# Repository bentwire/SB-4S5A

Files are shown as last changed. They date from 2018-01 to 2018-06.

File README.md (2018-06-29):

# SB-4S5A
4S1P 5000mAh smart battery

BOM: https://octopart.com/bom-tool/Ozuqnvew

![Image](https://lh3.googleusercontent.com/idjTSfCK8nfJFQzJIe7masI_trXQ7SMNvU6aqpUEBDsLIDIV-Hx3-JUPBGiGlPwAxTNEt7CckAo6dX-KWBZ0Mj_Hy6Guh6XXaXnfHWQ1HlrcL2ksQrWs3JgNRiBP9fyepql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)

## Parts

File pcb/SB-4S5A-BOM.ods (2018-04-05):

Qty | Line Item | Manufacturer | MPN | Octopart URL | Schematic Reference | Internal Part Number | Description | Total Qty (@ Batch Size: 10) | SKU | SKU | Packaging | Packaging | Unit Price (@ Batch Size: 10) | Unit Price (@ Batch Size: 10) | In Stock | In Stock | MOQ | MOQ | URL | URL | Distributor [Custom] | SKU [Custom] | Packaging [Custom] | Unit Price (@ Batch Size: 10) [Custom] | Line Total [Custom] | Batch Total [Custom] | In Stock [Custom] | MOQ [Custom] | URL [Custom] | Notes
 |  |  |  |  |  |  |  |  | Digi-Key | Mouser | Digi-Key | Mouser | Digi-Key | Mouser | Digi-Key | Mouser | Digi-Key | Mouser | Digi-Key | Mouser
2 | CSD17308Q3 | Texas Instruments | CSD17308Q3 | https://octopart.com/csd17308q3-texas+instruments-18530280 | Q1,Q2 |  |  | 20 | 296-27210-1-ND | CSD17308Q3 | Cut Tape |  | 0.904 | 0.676 | 23856 | 56 | 1 |  | https://octopart.com/click/track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 | https://octopart.com/click/track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 | Mouser | CSD17308Q3 |  | 0.676 | 1.352 | 13.52 | 56 |  | https://octopart.com/click/track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
1 | BQ40Z50RSMT-R1 | Texas Instruments | BQ40Z50RSMT-R1 | https://octopart.com/bq40z50rsmt-r1-texas+instruments-60770459 | U1 |  |  | 10 | 296-42424-1-ND | BQ40Z50RSMT-R1 | Cut Tape |  | 5.379 | 5.79 | 0 | 8385 | 1 |  | https://octopart.com/click/track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 | https://octopart.com/click/track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 | Digi-Key | 296-42424-1-ND | Cut Tape | 5.379 | 5.379 | 53.79 | 0 | 1 | https://octopart.com/click/track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
1 | 0.001 ohm 1% 1206 | Welwyn | LRMAM1206-R001FT5 | https://octopart.com/lrmam1206-r001ft5-welwyn-46392712 | R7 |  |  | 10 | 985-1544-1-ND | LRMAM1206-R001FT5 | Cut Tape |  | 0.404 | 0.38 | 5193 | 8269 | 1 |  | https://octopart.com/click/track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 | https://octopart.com/click/track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 | Mouser | LRMAM1206-R001FT5 |  | 0.38 | 0.38 | 3.8 | 8269 |  | https://octopart.com/click/track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
2 | 10K 1% 0402 | Yageo | RC0402FR-0710KL | https://octopart.com/rc0402fr-0710kl-yageo-55458461 | R15,R16 |  |  | 20 | 311-10.0KLRCT-ND | RC0402FR-0710KL | Cut Tape |  | 0.014 | 0.009 | 14082327 | 2372862 | 1 |  | https://octopart.com/click/track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 | https://octopart.com/click/track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 | Mouser | RC0402FR-0710KL |  | 0.009 | 0.018 | 0.18 | 2372862 |  | https://octopart.com/click/track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
2 | 5.1K 1% 0402 | Yageo | RC0402FR-075K1L | https://octopart.com/rc0402fr-075k1l-yageo-39844409 | R11,R14 |  |  | 20 | 311-5.10KLRCT-ND | RC0402FR-075K1L | Cut Tape |  | 0.014 | 0.009 | 1326600 | 308293 | 1 |  | https://octopart.com/click/track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 | https://octopart.com/click/track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 | Mouser | RC0402FR-075K1L |  | 0.009 | 0.018 | 0.18 | 308293 |  | https://octopart.com/click/track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
11 | 100 ohm 1% 0402 | Yageo | RC0402FR-07100RL | https://octopart.com/rc0402fr-07100rl-yageo-40952494 | R2,R3,R4,R5,R6,R8,R12,R17,R18,R19,R20 |  |  | 110 | 311-100LRCT-ND | RC0402FR-07100RL | Cut Tape |  | 0.0056 | 0.003 | 10041531 | 146034 | 1 |  | https://octopart.com/click/track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 | https://octopart.com/click/track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 | Digi-Key | 311-100LRCT-ND | Cut Tape | 0.0056 | 0.0616 | 0.616 | 10041531 | 1 | https://octopart.com/click/track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
2 | 10M 5% 0402 | Yageo | RC0402FR-0710ML | https://octopart.com/rc0402fr-0710ml-yageo-42336635 | R10,R13 |  |  | 20 | 311-10.0MLRCT-ND | RC0402FR-0710ML | Cut Tape |  | 0.013 | 0.01 | 530653 | 92341 | 1 |  | https://octopart.com/click/track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 | https://octopart.com/click/track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 | Mouser | RC0402FR-0710ML |  | 0.01 | 0.02 | 0.2 | 92341 |  | https://octopart.com/click/track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
4 | NTC THERMISTOR 10K OHM 1% 0402 | Murata | NCP15XH103F03RC | https://octopart.com/ncp15xh103f03rc-murata-746463 | TH1, TH2, TH3, TH4 |  |  | 40 | 490-4801-1-ND | NCP15XH103F03RC | Cut Tape |  | 0.0988 | 0.107 | 315244 | 140120 | 1 |  | https://octopart.com/click/track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 | https://octopart.com/click/track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 | Digi-Key | 490-4801-1-ND | Cut Tape | 0.0988 | 0.3952 | 3.952 | 315244 | 1 | https://octopart.com/click/track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
1 | BAT54HT1G | ON Semiconductor | BAT54HT1G | https://octopart.com/bat54ht1g-on+semiconductor-39616 | D1 |  |  | 10 | BAT54HT1GOSCT-ND | BAT54HT1G | Cut Tape |  | 0.225 | 0.167 | 150710 | 19391 | 1 |  | https://octopart.com/click/track?country=US&ak=68b25f31&sig=07c835d&sid=459&ppid=39616&vpid=1203010&ct=offers | https://octopart.com/click/track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 | Mouser | BAT54HT1G |  | 0.167 | 0.167 | 1.67 | 19391 |  | https://octopart.com/click/track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
1 | 2V7002LT1G | ON Semiconductor | 2V7002LT1G | https://octopart.com/2v7002lt1g-on+semiconductor-22133360 | Q3 |  |  | 10 | 2V7002LT1GOSCT-ND | 2V7002LT1G | Cut Tape |  | 0.251 | 0.16 | 100230 | 11900 | 1 |  | https://octopart.com/click/track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 | https://octopart.com/click/track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 | Digi-Key | 2V7002LT1GOSCT-ND | Cut Tape | 0.251 | 0.251 | 2.51 | 100230 | 1 | https://octopart.com/click/track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
1 | 0 ohm jumper 0402 | Yageo | RC0402JR-070RL | https://octopart.com/rc0402jr-070rl-yageo-55434392 | R1 |  |  | 10 | 311-0.0JRCT-ND | RC0402JR-070RL | Cut Tape |  | 0.01 | 0.009 | 0 | 1889345 | 1 |  | https://octopart.com/click/track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 | https://octopart.com/click/track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 | Mouser | RC0402JR-070RL |  | 0.009 | 0.009 | 0.09 | 1889345 |  | https://octopart.com/click/track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
5 | 0.1uF 25V X5R/X7R | TDK | C1005X5R1H104K050BB | https://octopart.com/c1005x5r1h104k050bb-tdk-25947547 | C1,C2,C3,C4,C5 |  |  | 10 | 445-5942-1-ND | C1005X5R1H104K050BB | Cut Tape |  | 0.093 | 0.091 | 3757988 | 146262 | 1 |  | https://octopart.com/click/track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 | https://octopart.com/click/track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 | Mouser | C1005X5R1H104K050BB |  | 0.091 | 0.091 | 0.91 | 146262 |  | https://octopart.com/click/track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
1 | 2.2uF 10V X5R/X7R | Murata | GCM1555C1H680JA16D | https://octopart.com/gcm1555c1h680ja16d-murata-7894738 | C6 |  |  | 10 | 490-12653-1-ND | GCM1555C1H680JA16D | Cut Tape |  | 0.05 | 0.052 | 55591 | 43435 | 1 |  | https://octopart.com/click/track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 | https://octopart.com/click/track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 | Digi-Key | 490-12653-1-ND | Cut Tape | 0.05 | 0.05 | 0.5 | 55591 | 1 | https://octopart.com/click/track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
34

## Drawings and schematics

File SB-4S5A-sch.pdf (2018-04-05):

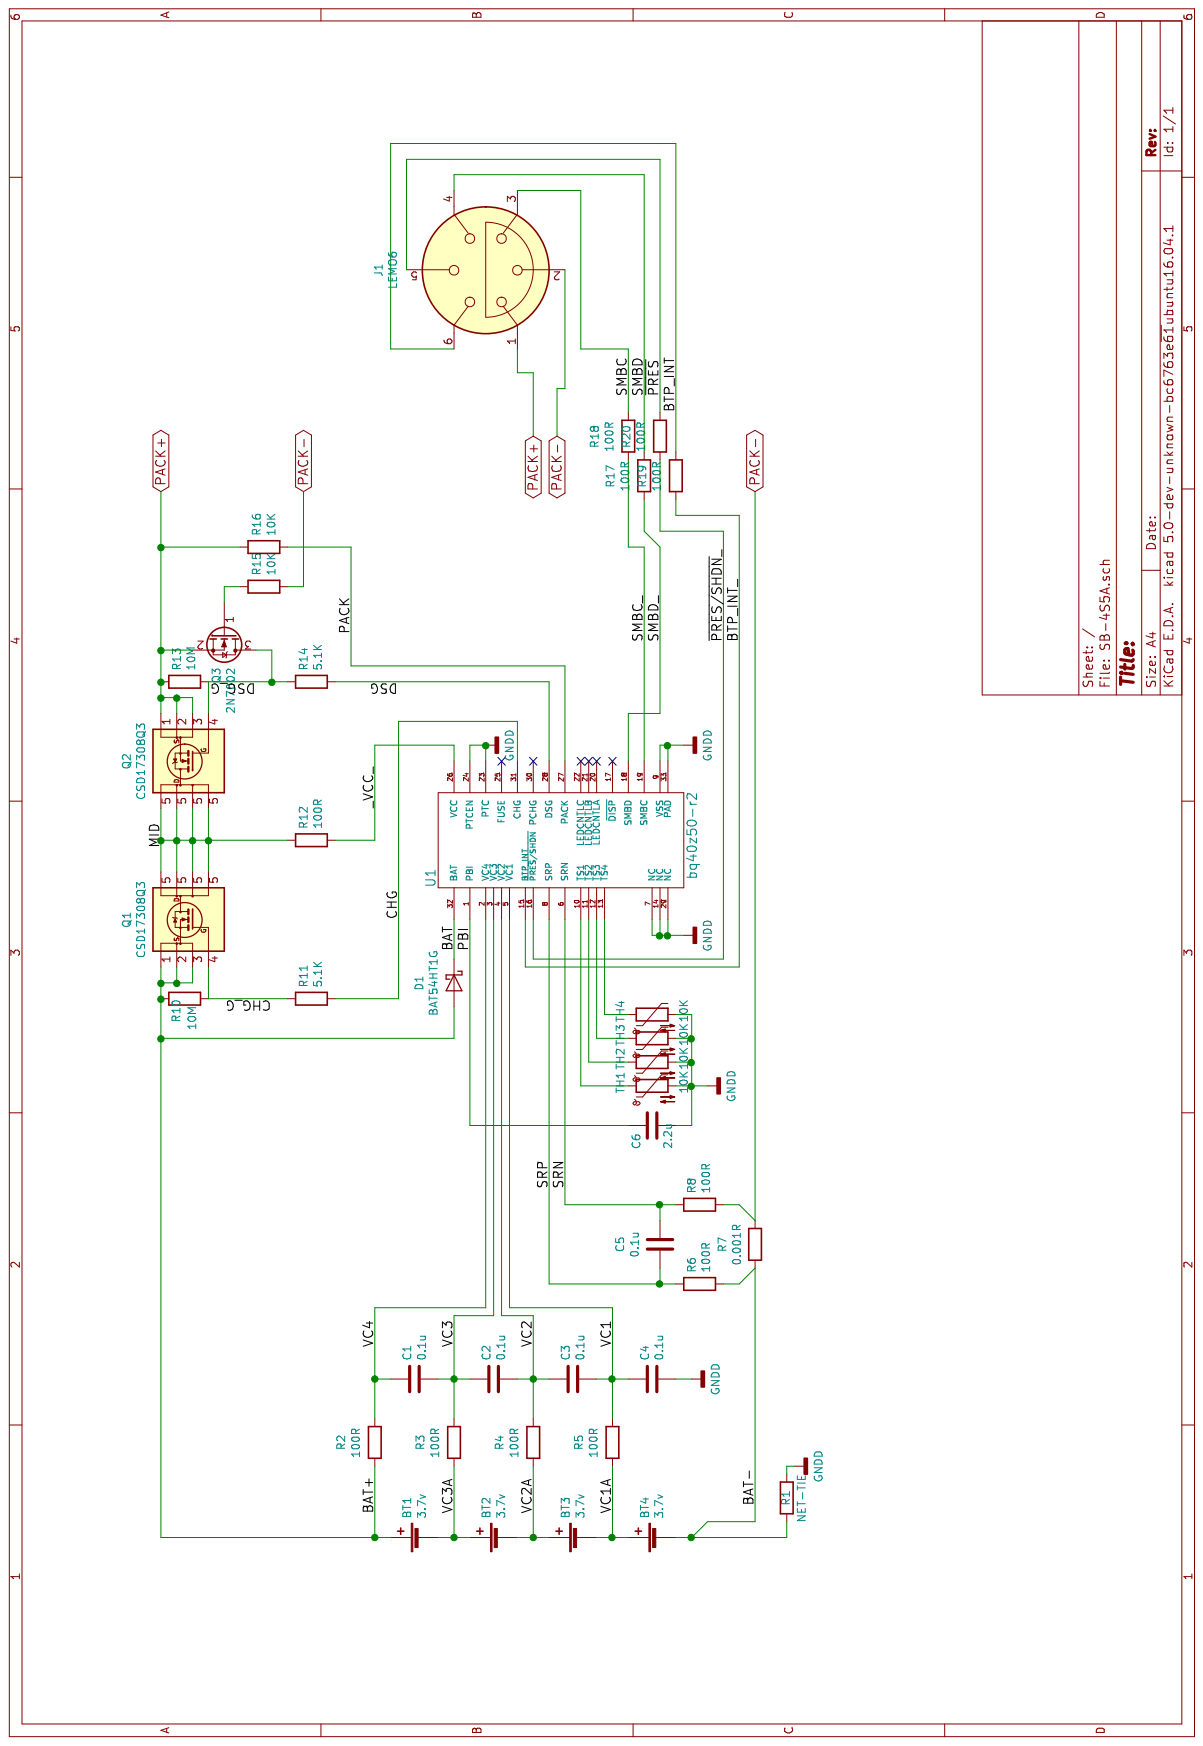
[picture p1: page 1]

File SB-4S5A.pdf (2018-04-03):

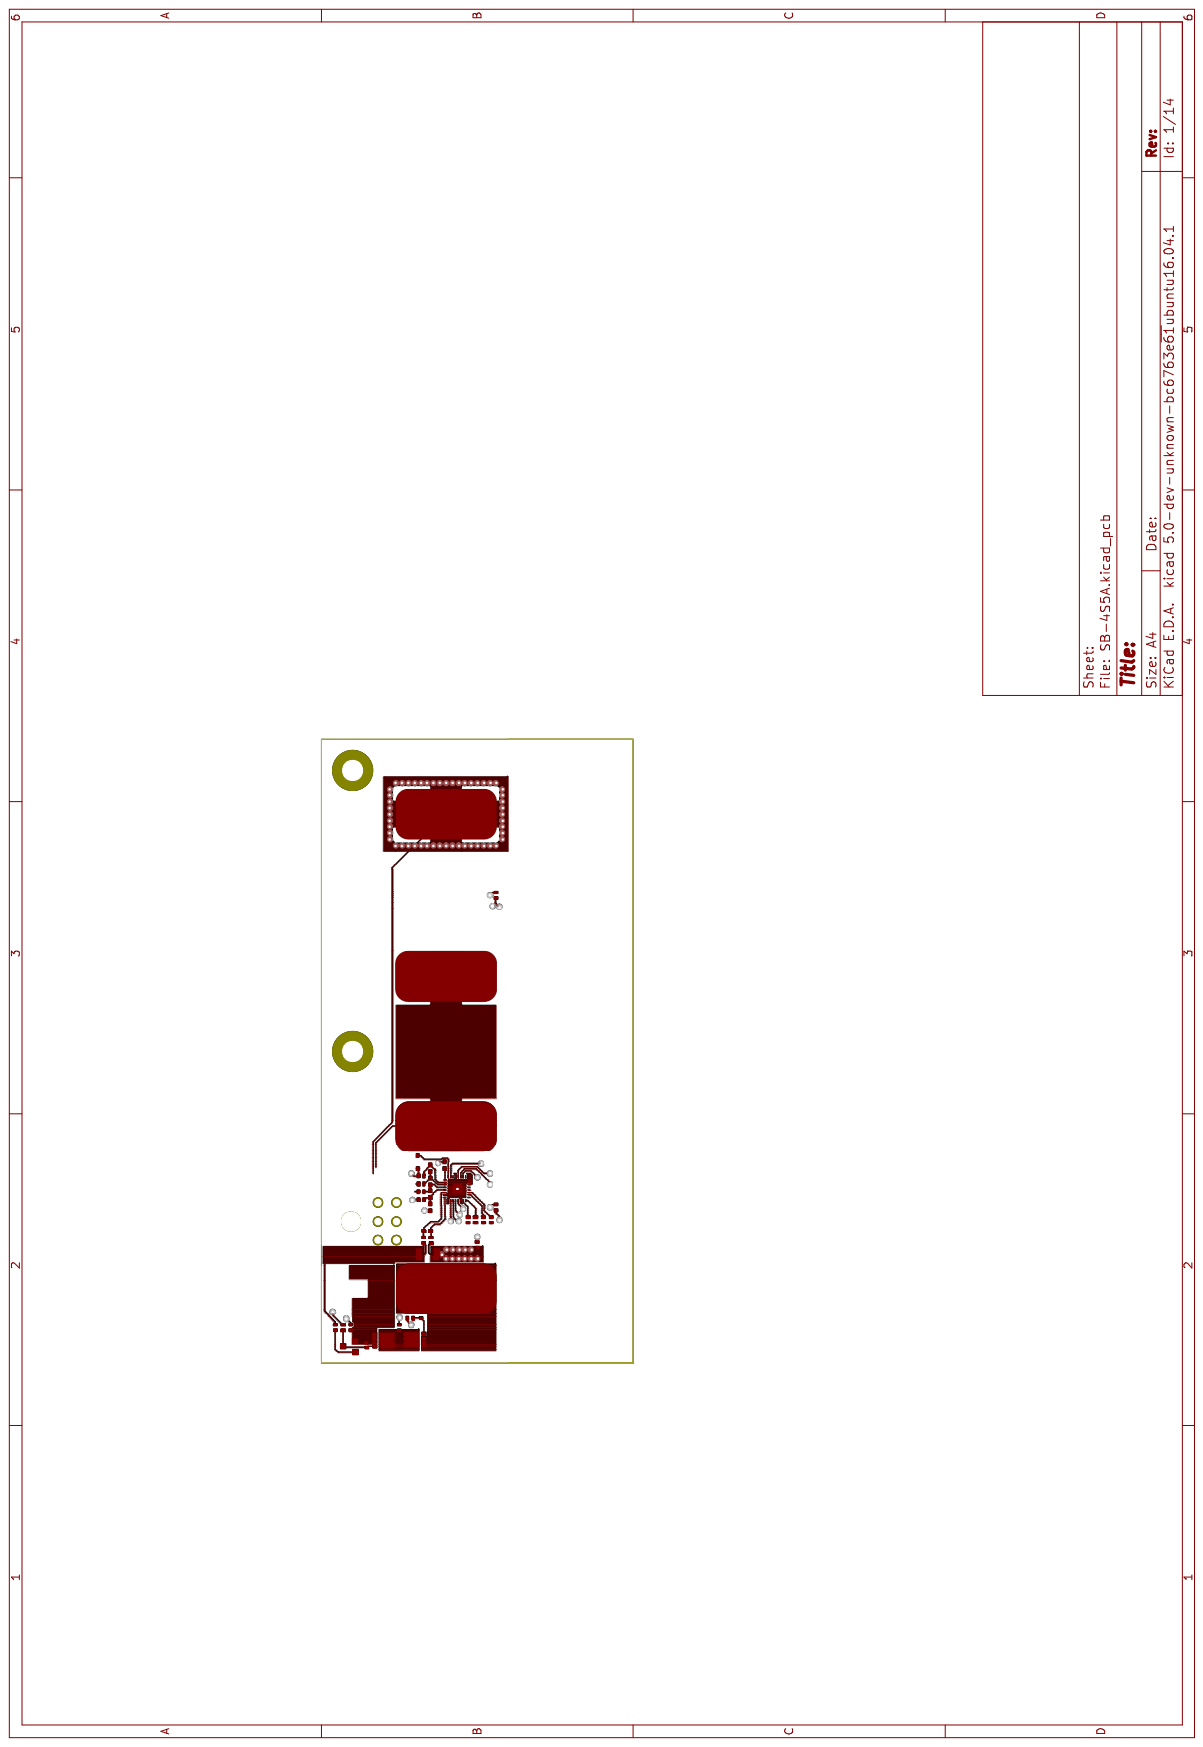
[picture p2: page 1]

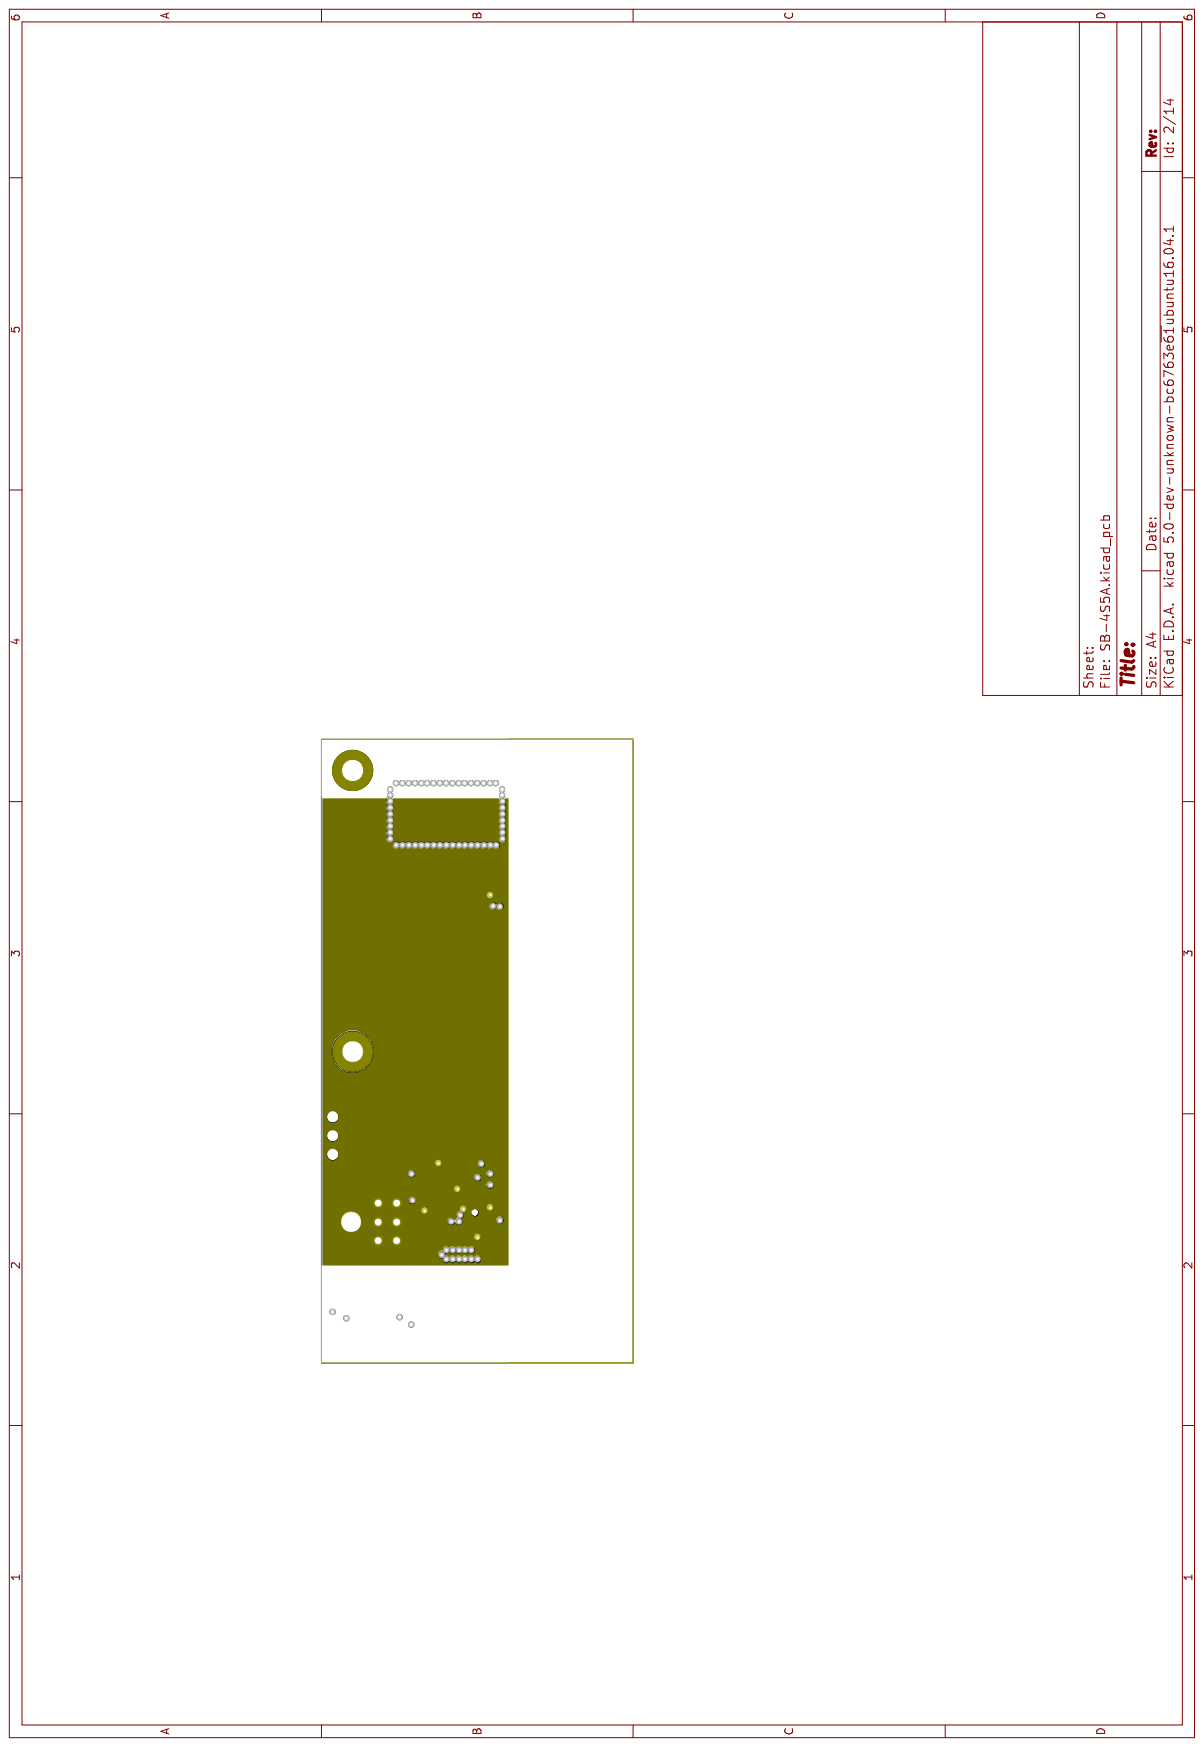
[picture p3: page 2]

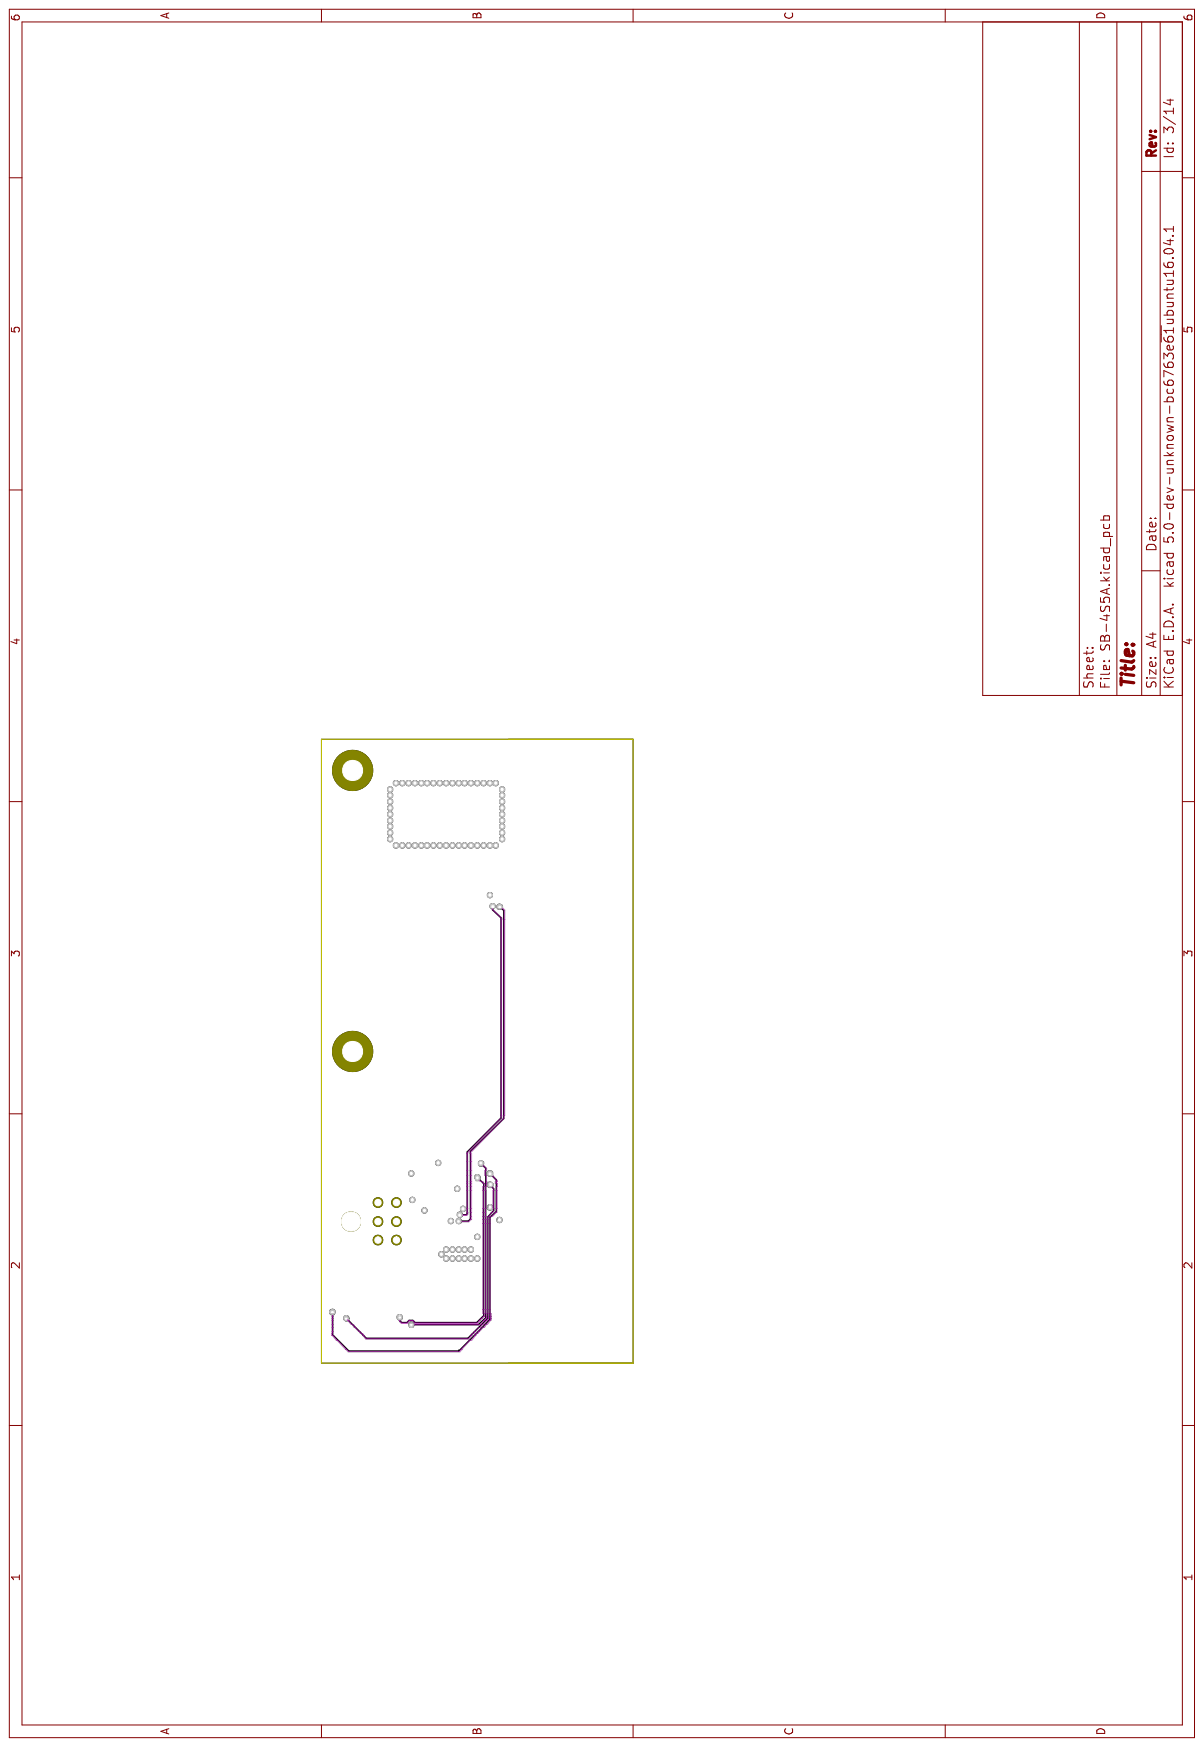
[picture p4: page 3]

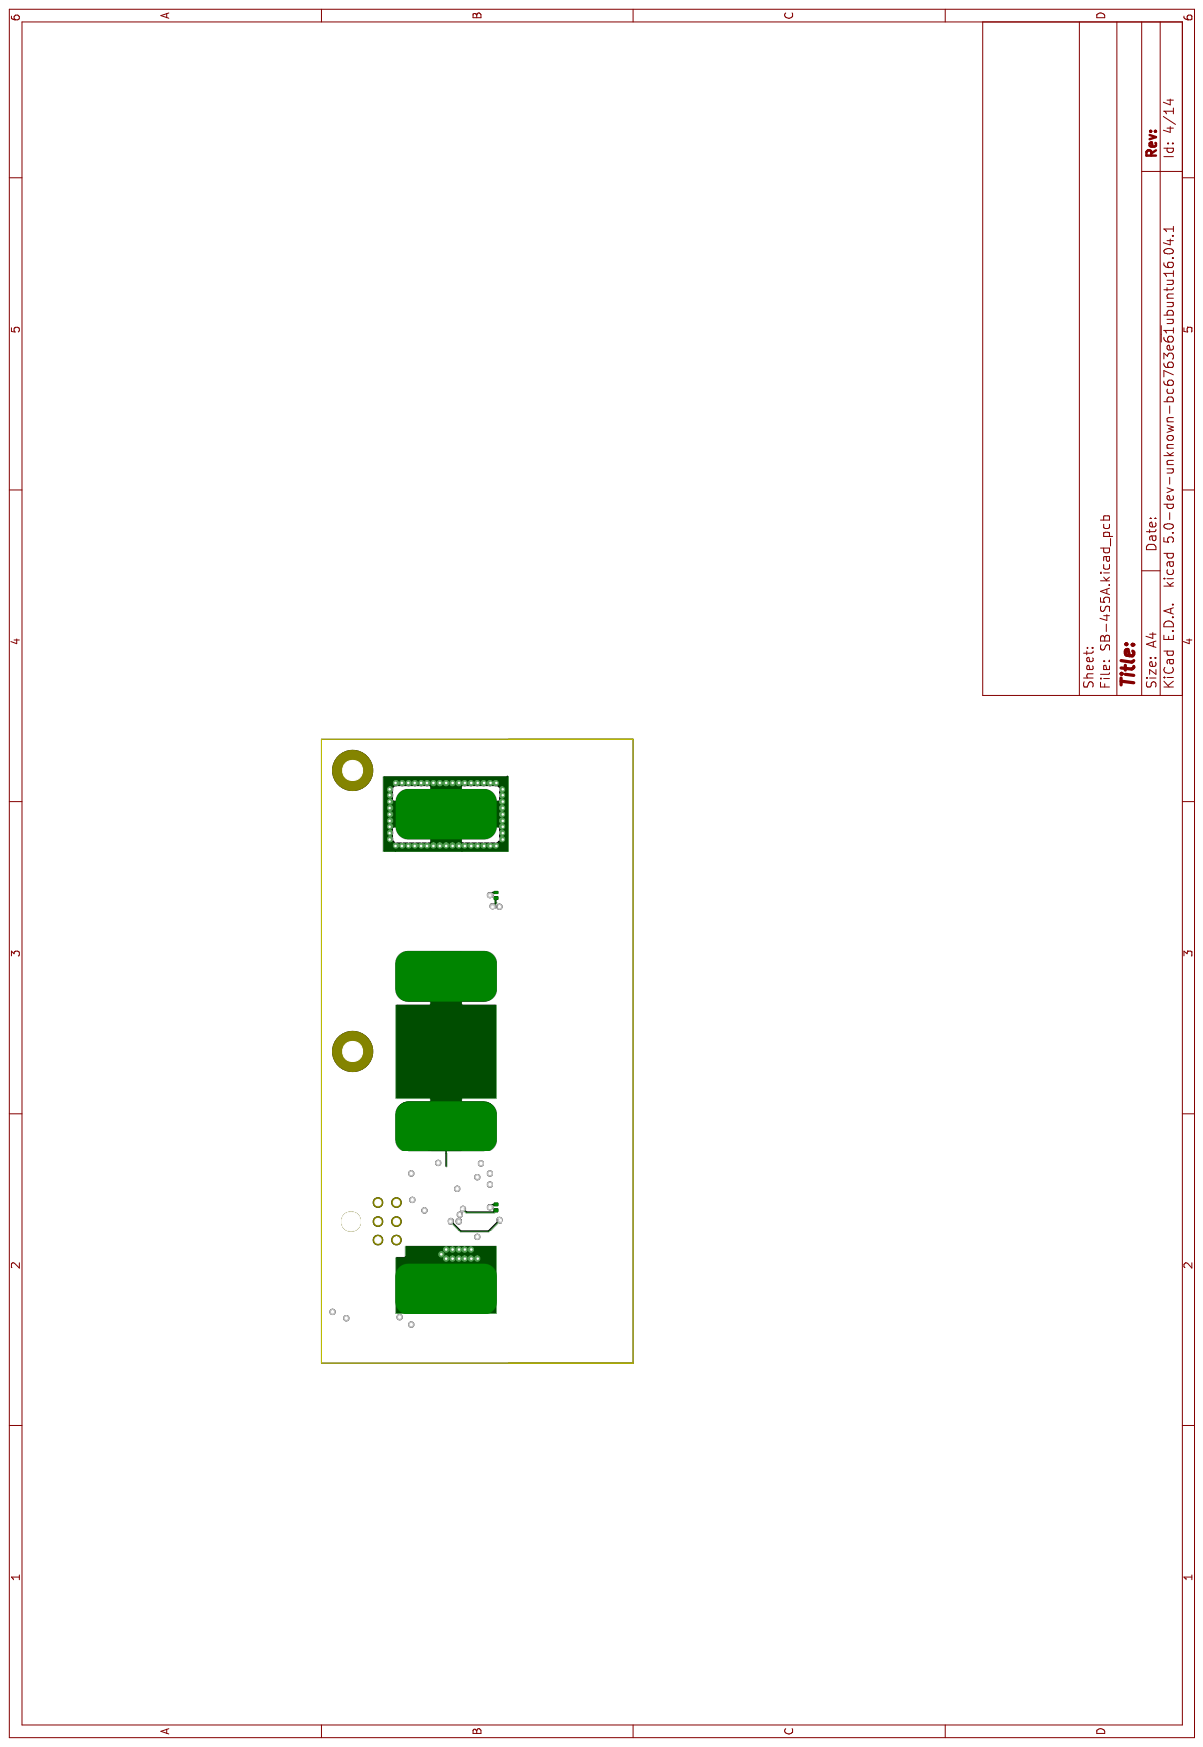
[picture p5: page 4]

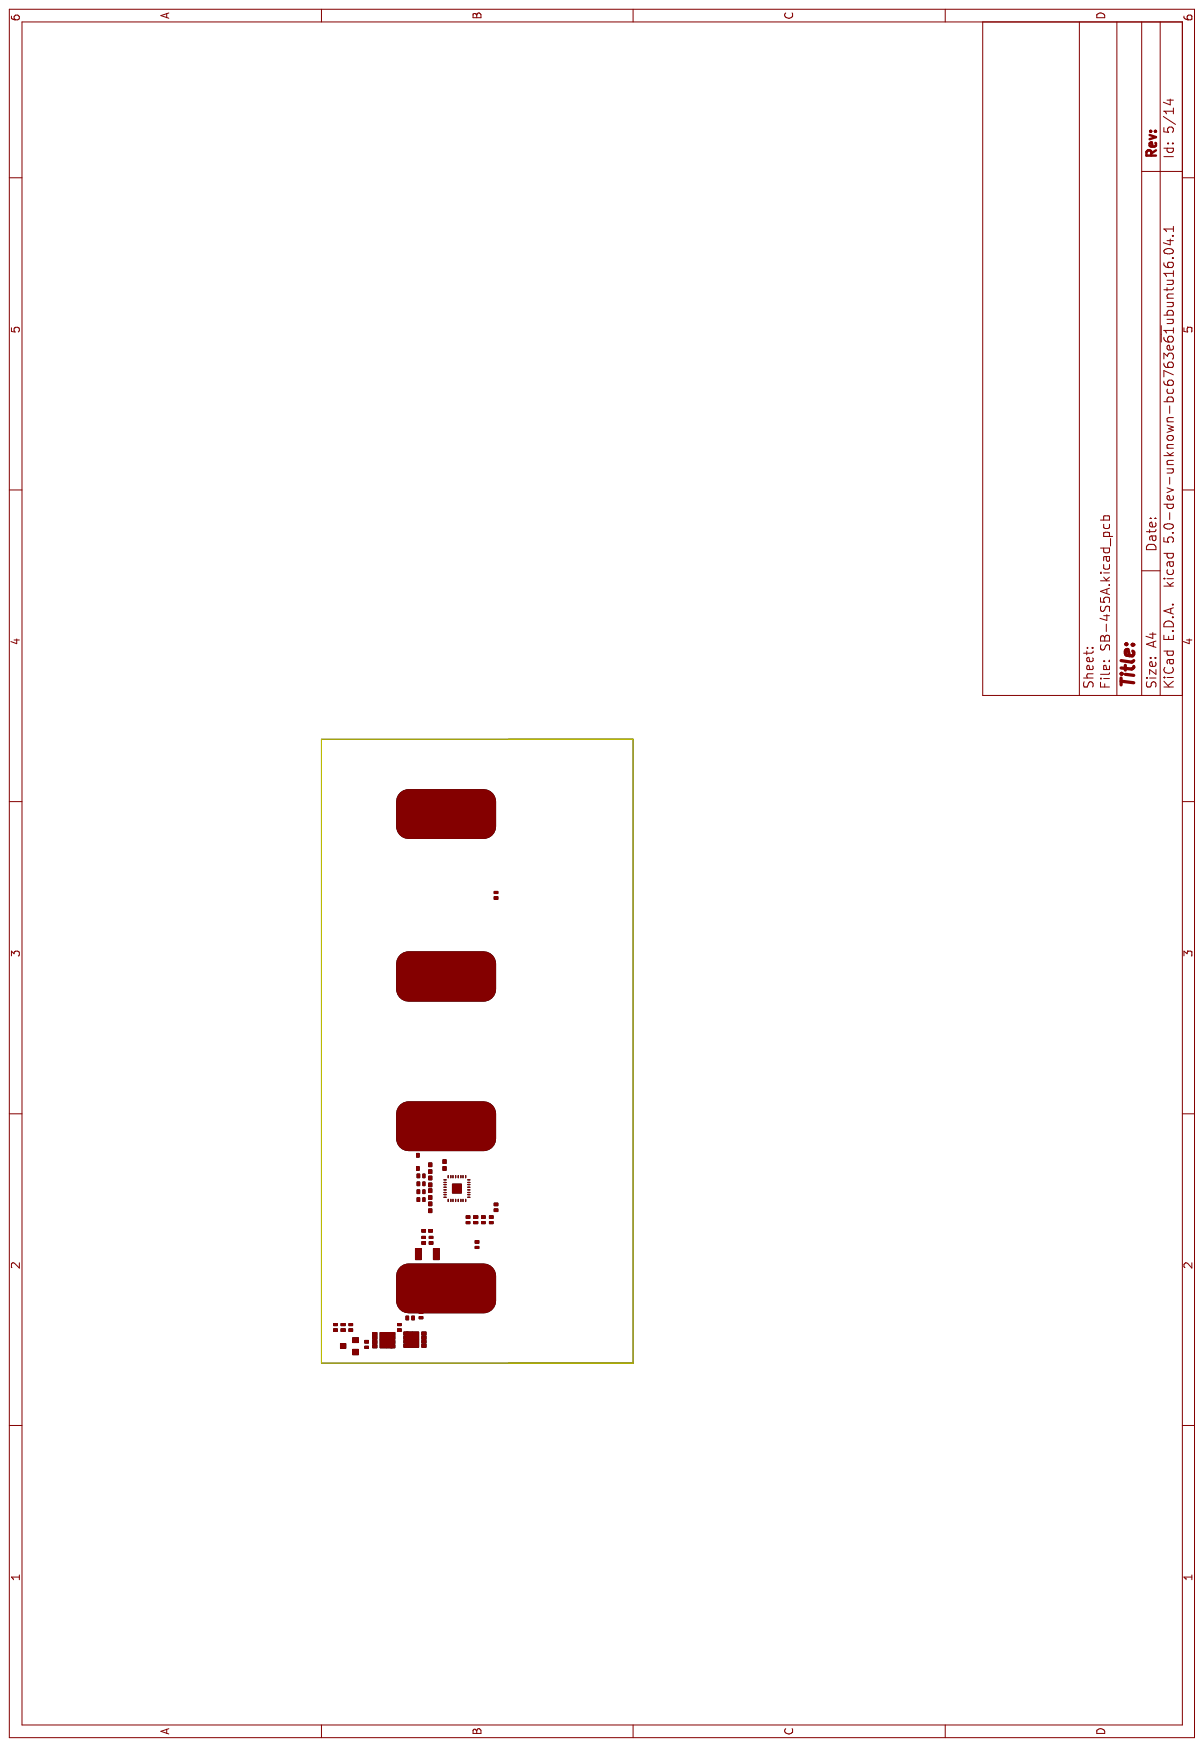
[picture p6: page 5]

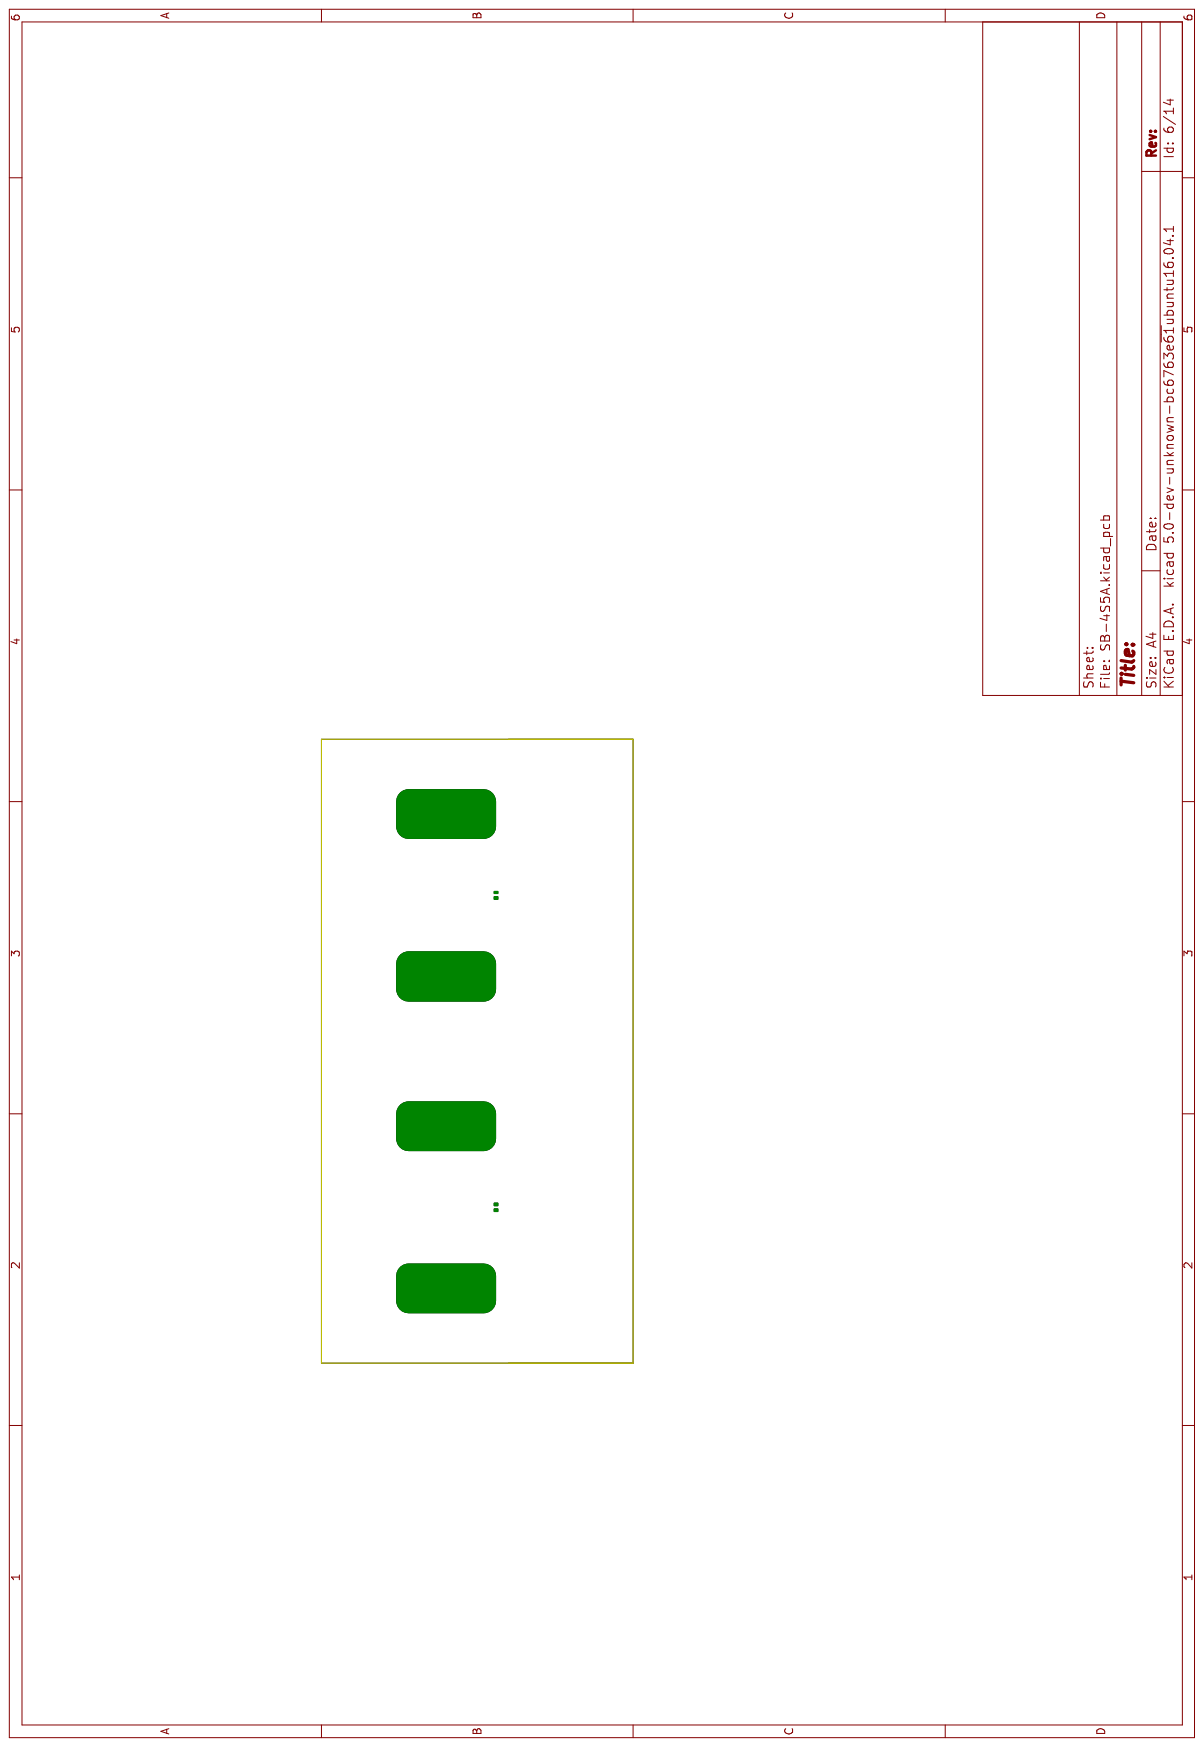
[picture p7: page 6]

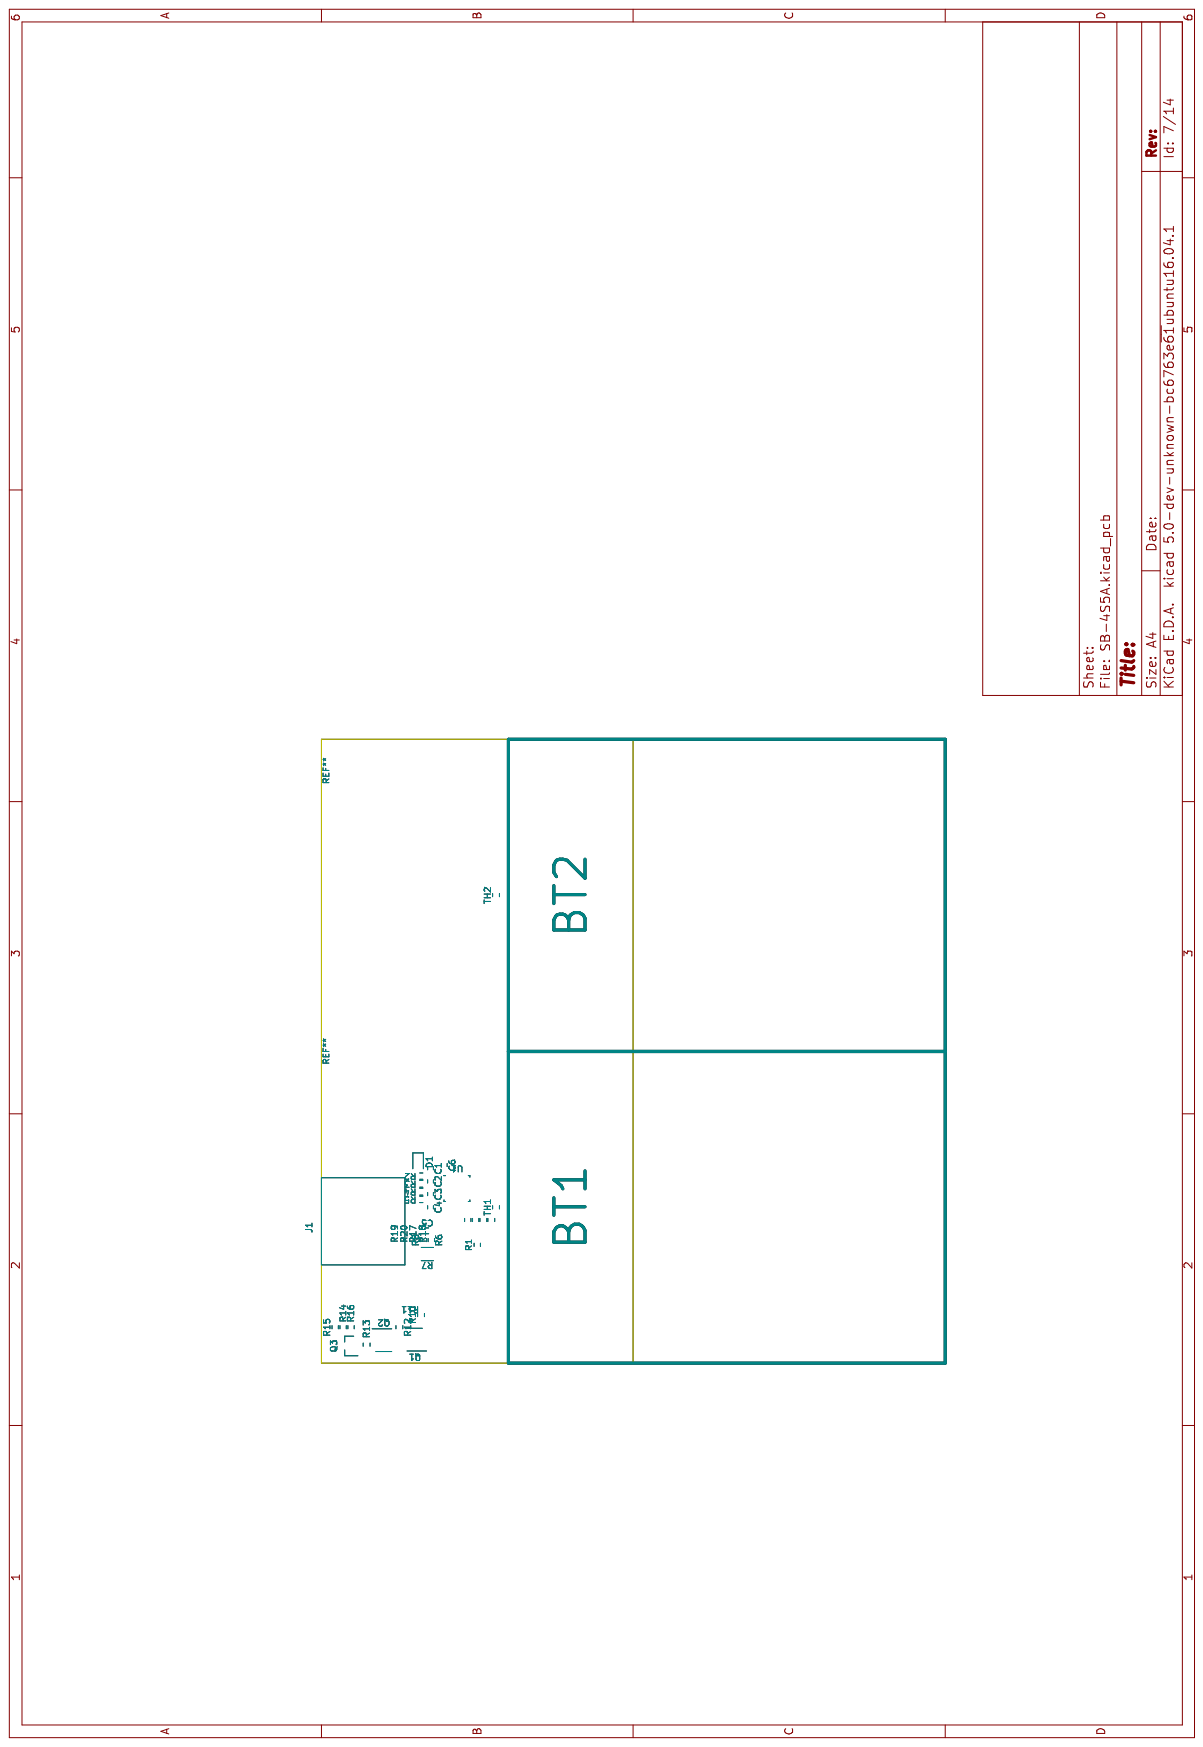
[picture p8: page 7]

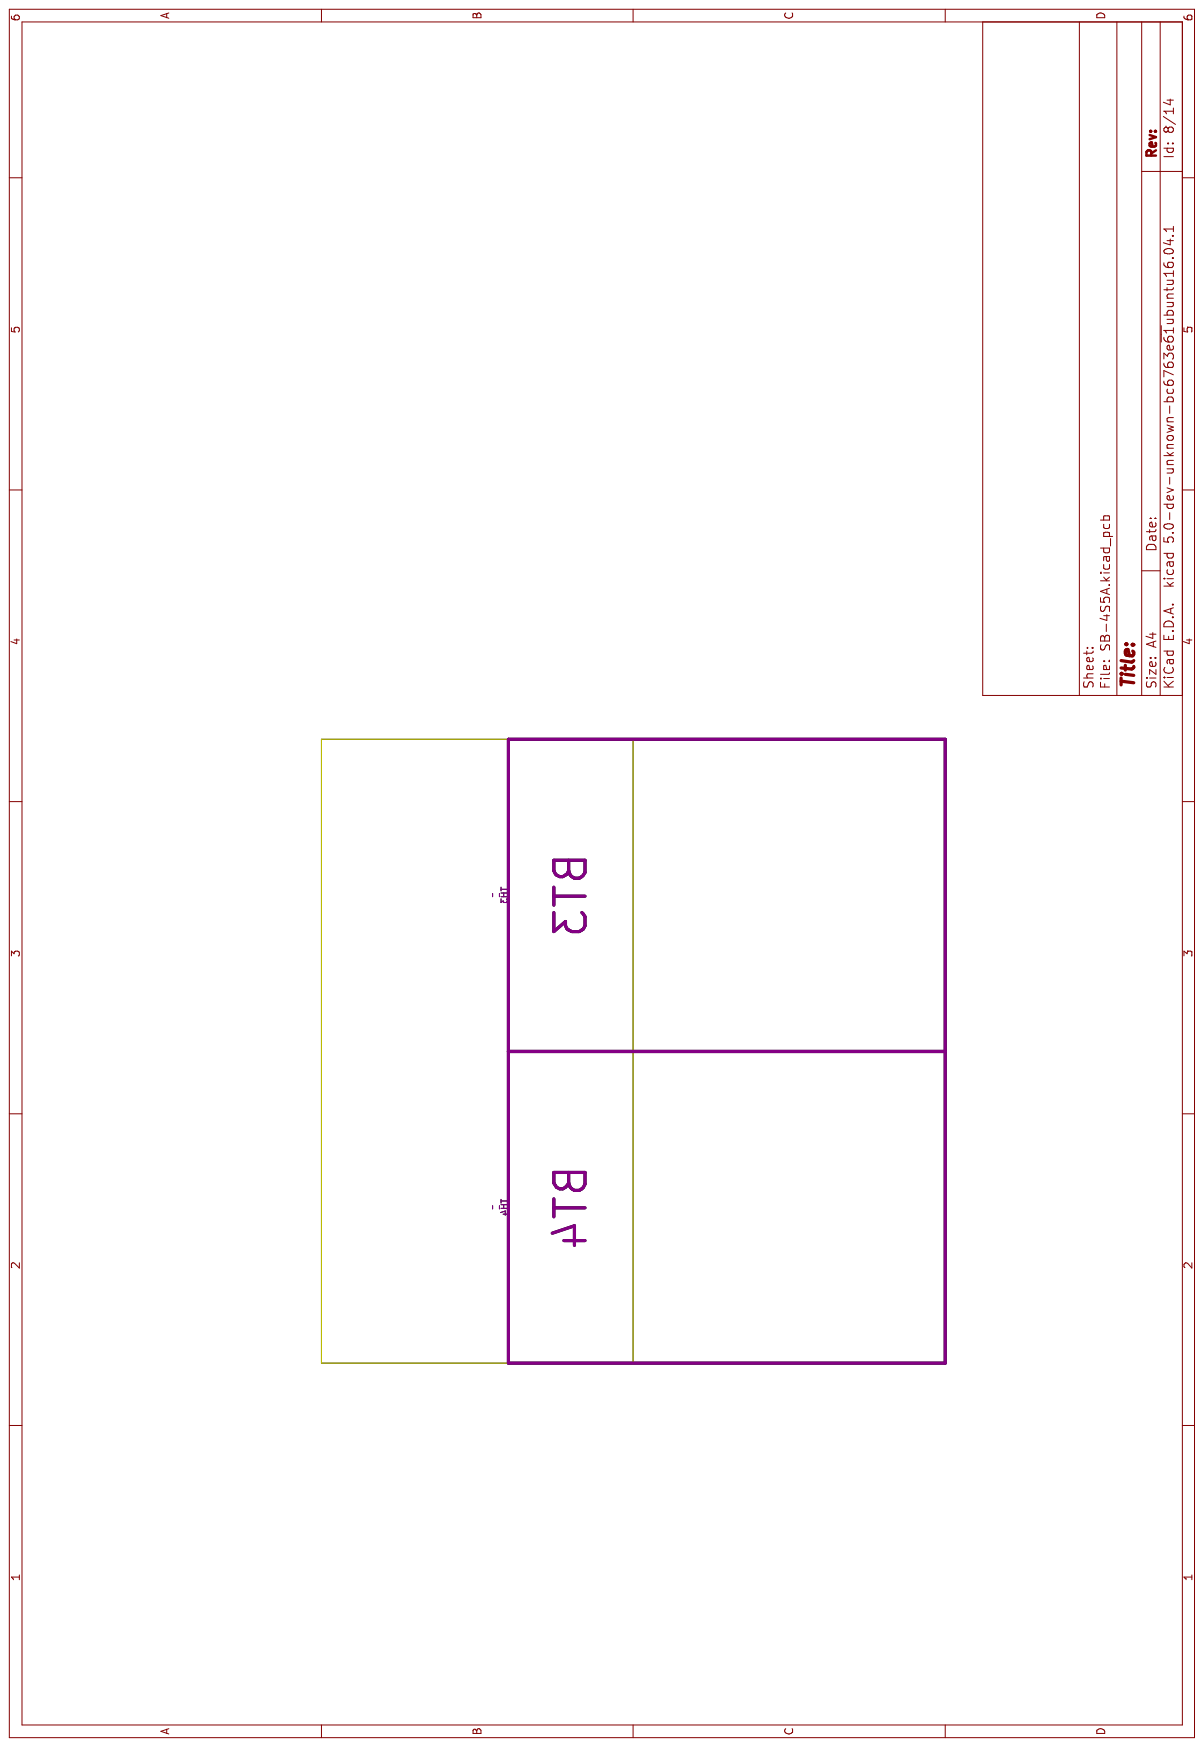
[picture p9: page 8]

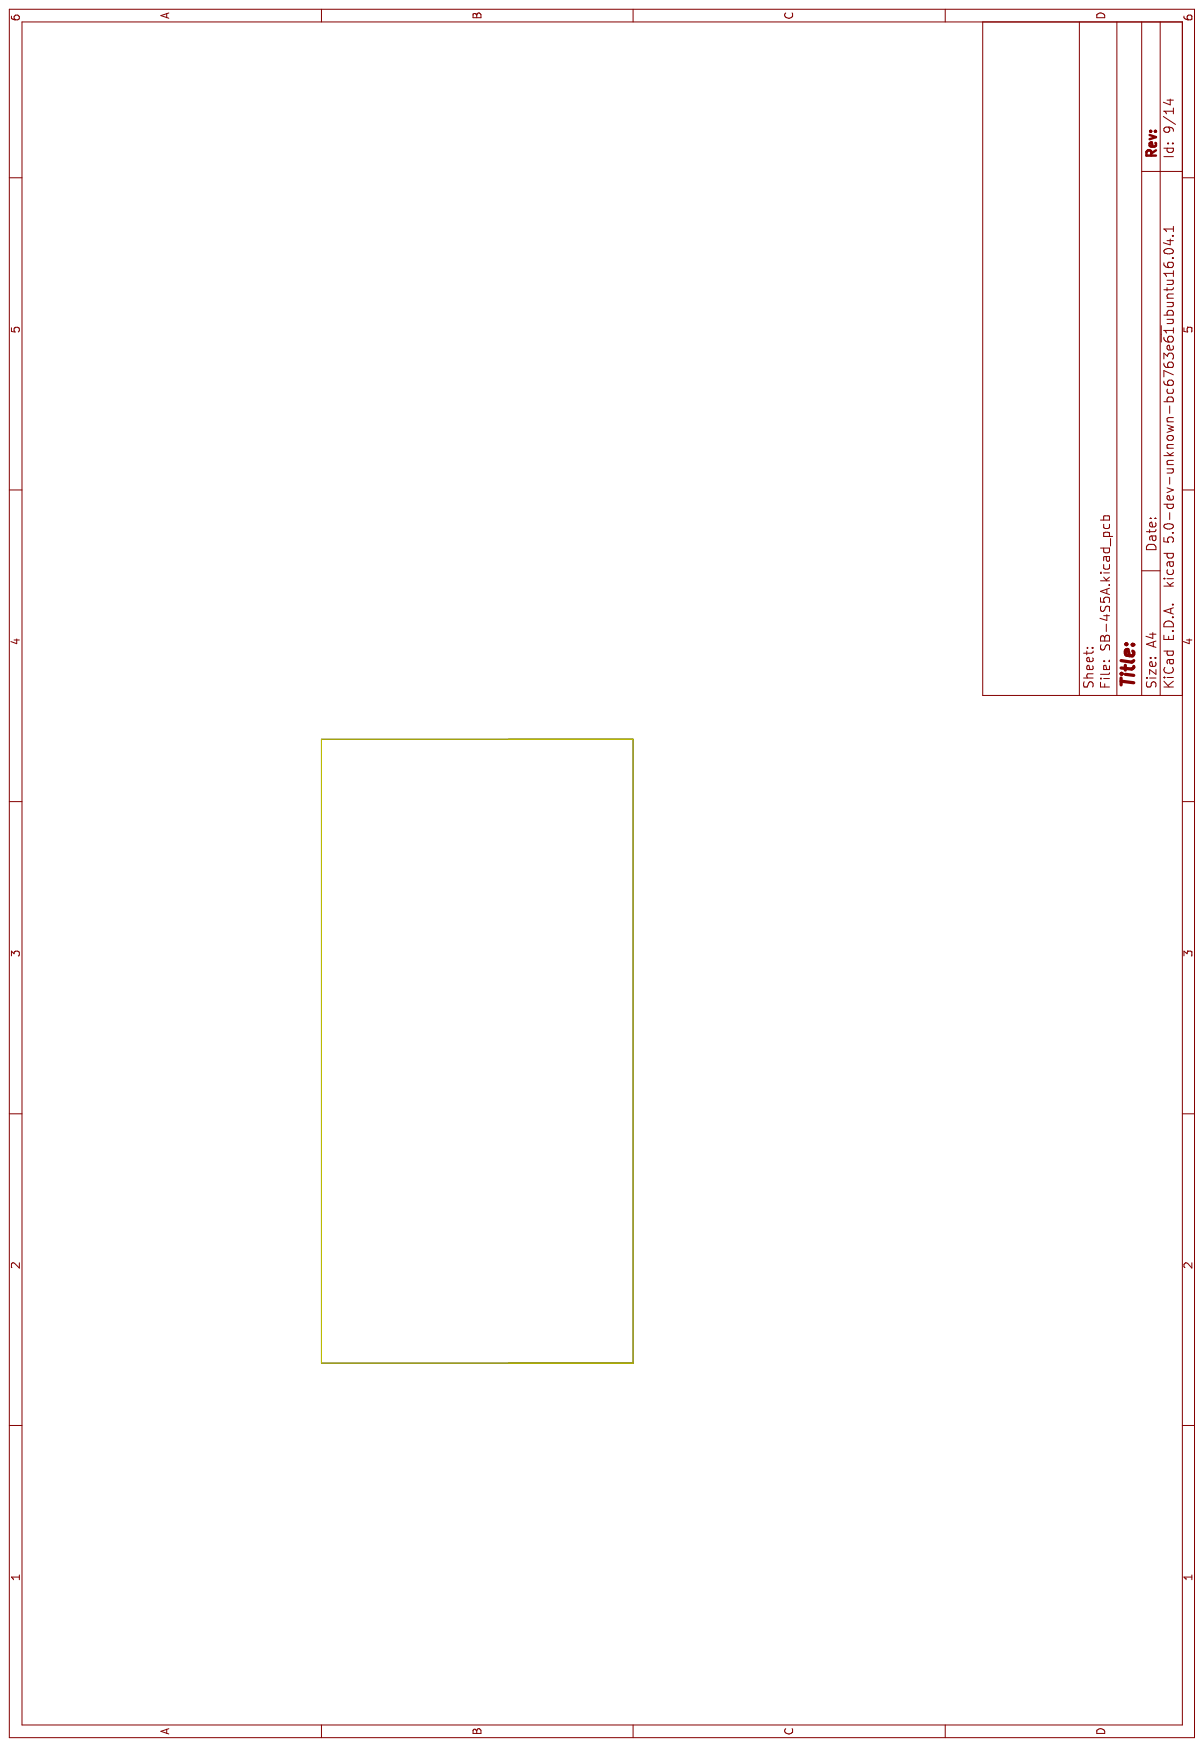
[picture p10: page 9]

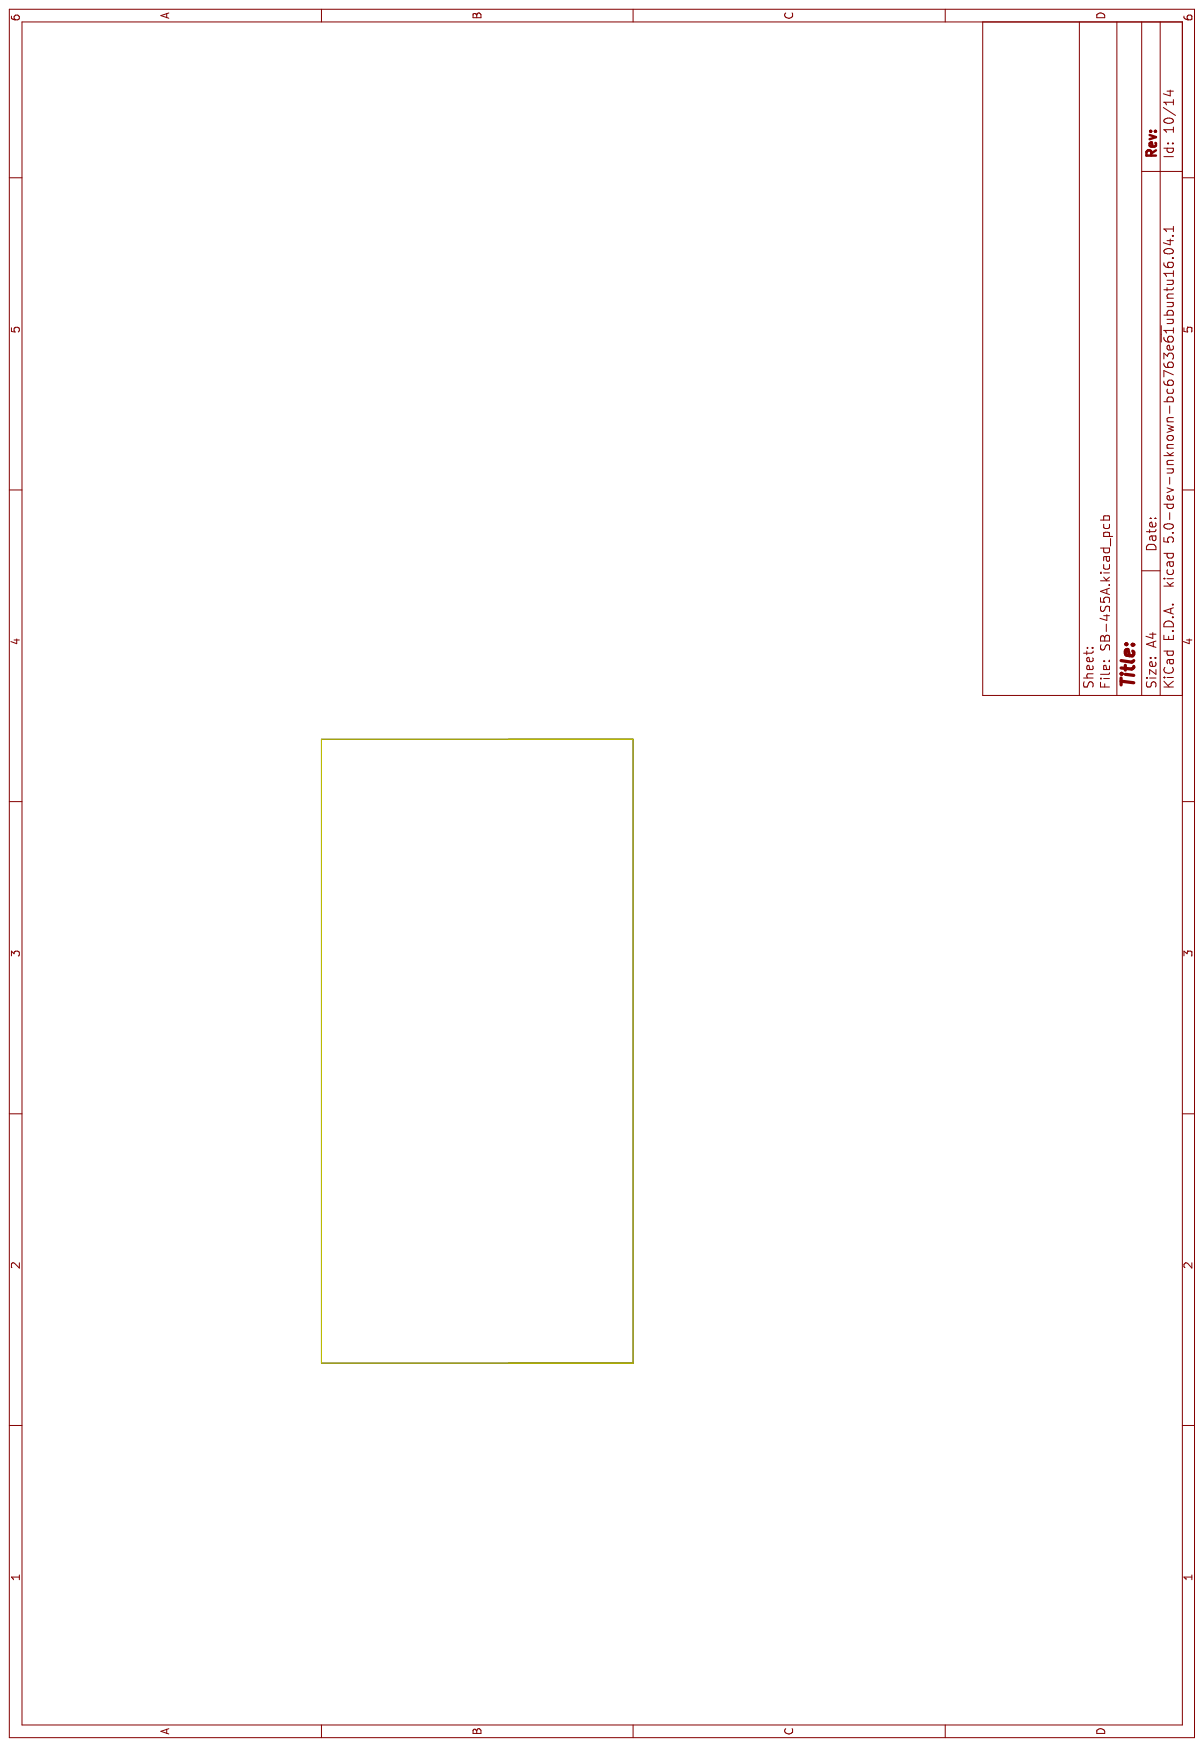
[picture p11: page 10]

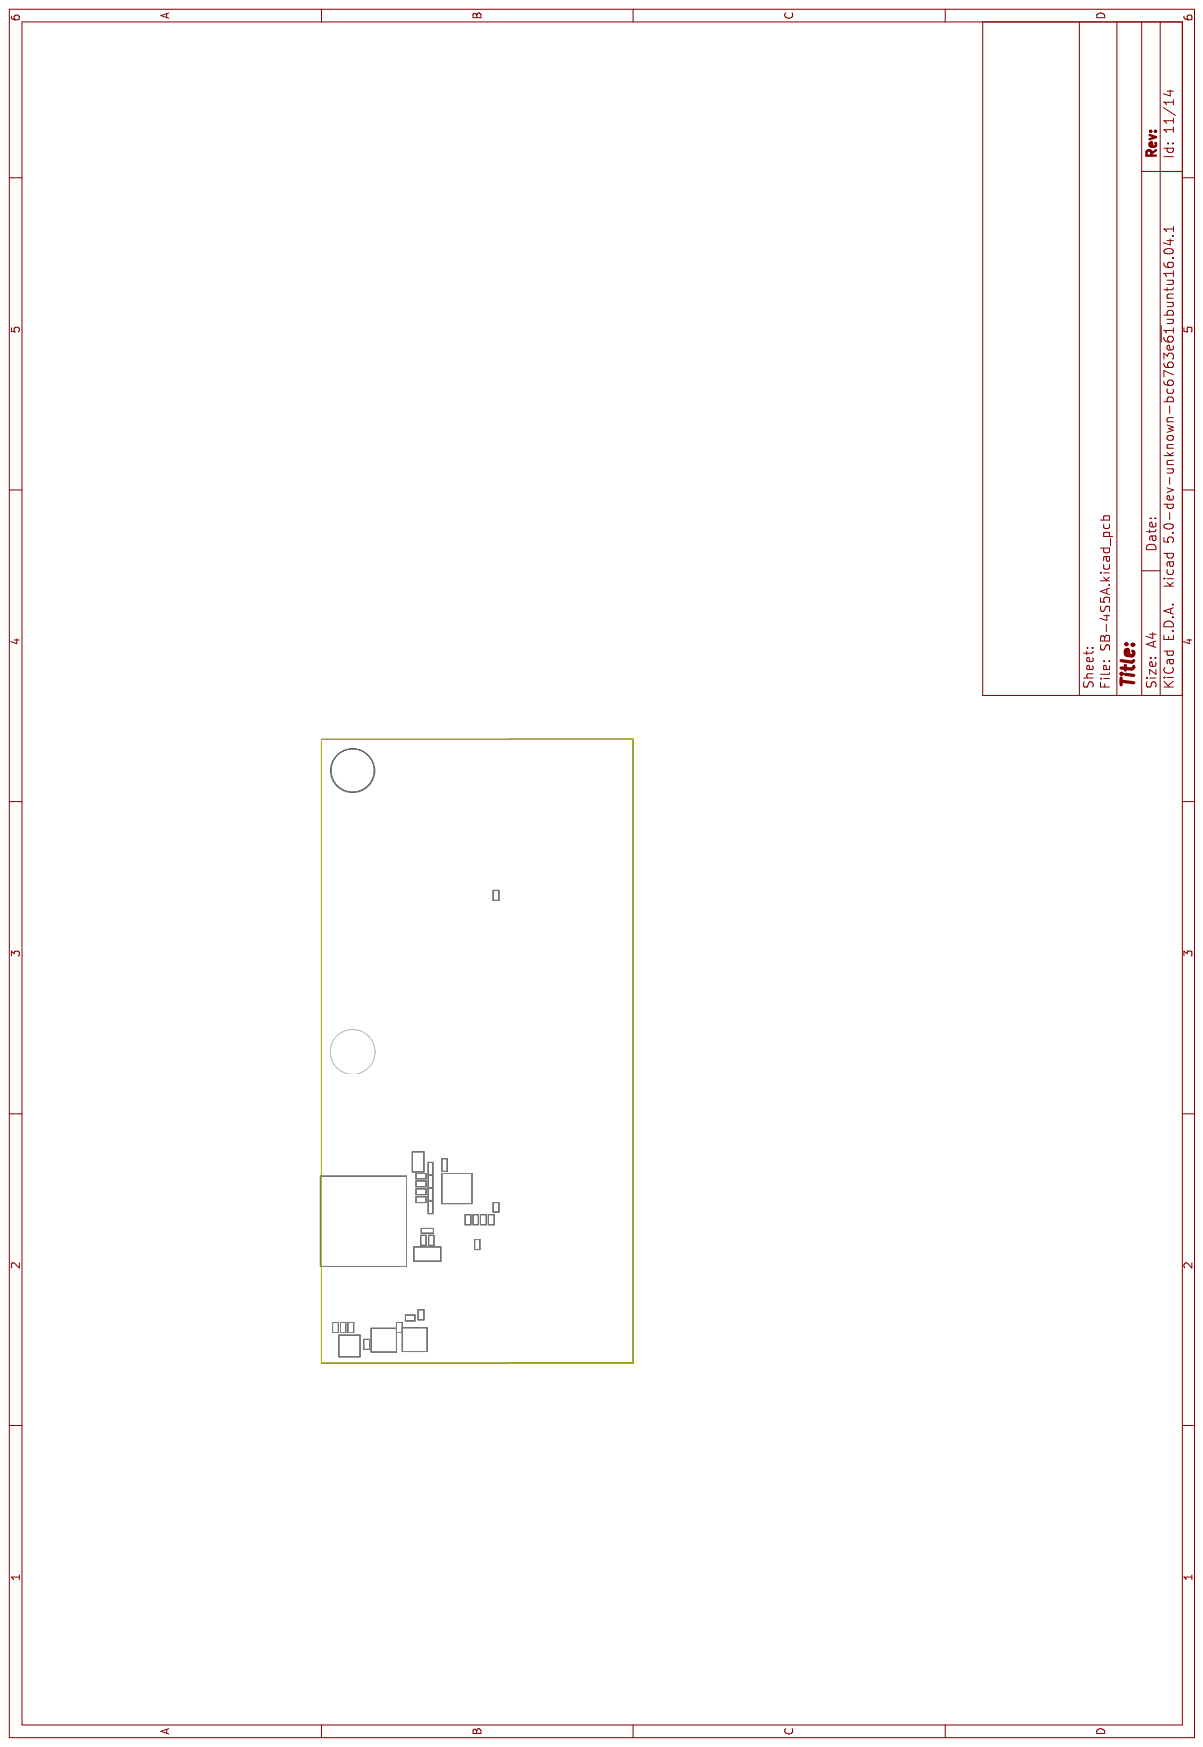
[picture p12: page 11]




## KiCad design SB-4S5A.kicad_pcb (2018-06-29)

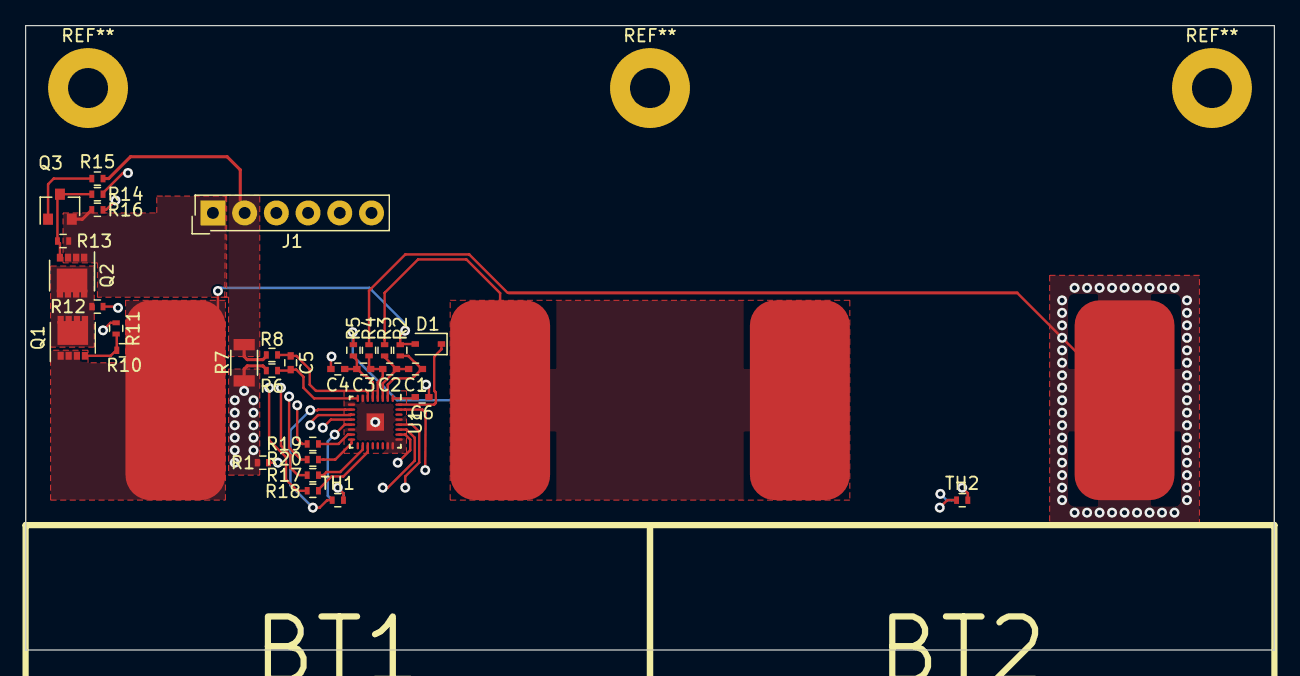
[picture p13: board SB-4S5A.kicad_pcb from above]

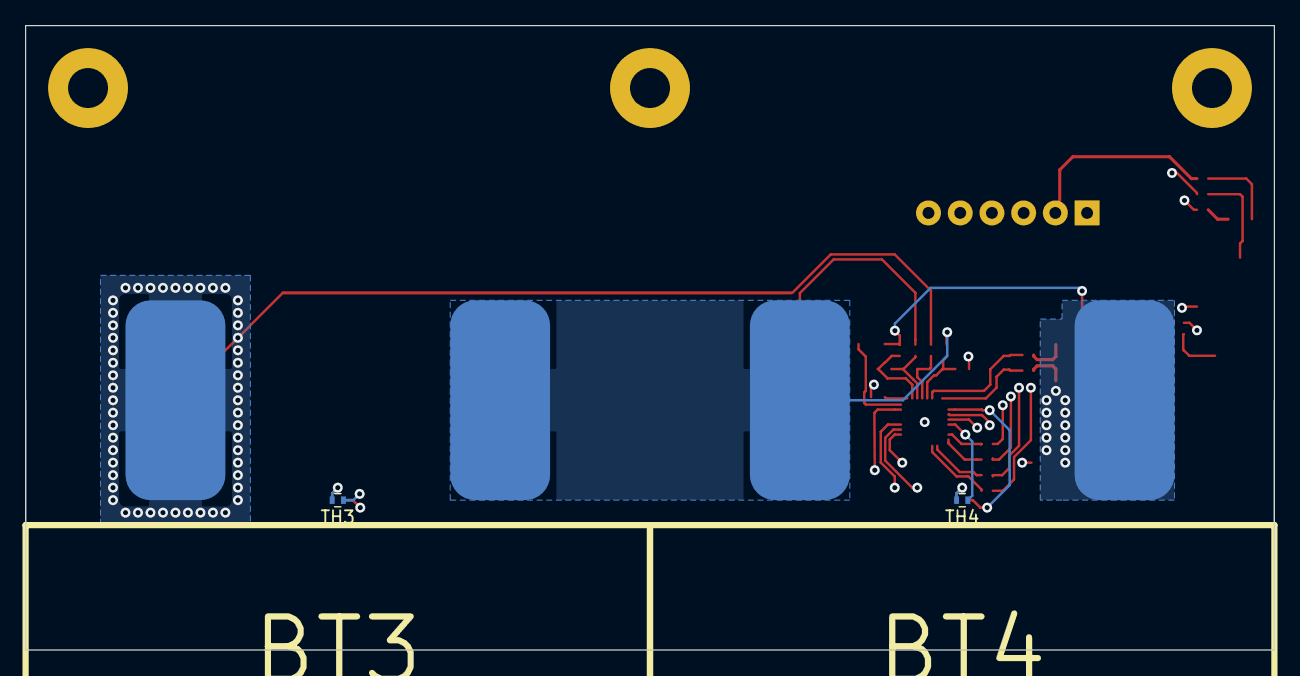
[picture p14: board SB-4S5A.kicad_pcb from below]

Board: 4 copper layers, 100.0 x 50.0 mm, 39 parts (4 on the bottom side), 36 nets.

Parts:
BT1, BT2, BT3, BT4: 3.7v; 105070
C1, C2, C3, C4, C5: 0.1u; C_0402
C6: 2.2u; C_0402
D1: BAT54HT1G; D_SOD-323
J1: LEMO6; SL-106-X-XX_1x06
Q1, Q2: CSD17308Q3; VSON-8_3.3x3.3mm_Pitch0.65mm_NexFET
Q3: 2N7002; SOT-23
R1: NET-TIE; R_0402
R2, R3, R4, R5, R6, R8, R12, R17, R18, R19, R20: 100R; R_0402
R7: 0.001R; R_1206
R10, R13: 10M; R_0402
R11, R14: 5.1K; R_0402
R15, R16: 10K; R_0402
TH1, TH2, TH3, TH4: 10K; R_0402
U1: bq40z50-r2; QFN-32_EP_3.8x3.8_Pitch0.4mm

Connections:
/BAT: D1.1, U1.32
/BAT+: BT1.1, D1.2, Q1.1, Q1.2, Q1.3, R2.1, R10.2
/BAT-: BT4.2, R1.1, R6.1, R7.2
/BTP_INT: J1.6, R19.2
/BTP_INT_: R19.1, U1.15
/CHG: R11.1, U1.31
/CHG_G: Q1.4, R10.1, R11.2
/DSG: R14.1, U1.28
/DSG_G: Q2.4, Q3.3, R13.1, R14.2
/MID: Q1.5, Q2.5, R12.2
/PACK: R16.2, U1.27
/PBI: C6.1, U1.1
/SMBC: J1.3, R18.2
/SMBC_: R18.1, U1.19
/SMBD: J1.4, R17.2
/SMBD_: R17.1, U1.18
/SRN: C5.1, R8.2, U1.6
/SRP: C5.2, R6.2, U1.8
/VC1: C3.2, C4.1, R5.2, U1.5
/VC1A: BT3.2, BT4.1, R5.1
/VC2: C2.2, C3.1, R4.2, U1.4
/VC2A: BT2.2, BT3.1, R4.1
/VC3: C1.2, C2.1, R3.2, U1.3
/VC3A: BT1.2, BT2.1, R3.1
/VC4: C1.1, R2.2, U1.2
/_VCC_: R12.1, U1.26
/~PRES/SHDN~_: R20.1, U1.16
/~PRES~: J1.5, R20.2
GNDD: C4.2, C6.2, R1.2, TH1.2, TH2.2, TH3.2, TH4.2, U1.7, U1.9, U1.14, U1.23, U1.24, U1.25, U1.29, U1.33
unnamed: Q3.1, R15.1
unnamed: TH1.1, U1.10
unnamed: TH2.1, U1.11
unnamed: TH3.1, U1.12
unnamed: TH4.1, U1.13
PACK+: J1.1, Q2.1, Q2.2, Q2.3, Q3.2, R13.2, R16.1
PACK-: J1.2, R7.1, R8.1, R15.2

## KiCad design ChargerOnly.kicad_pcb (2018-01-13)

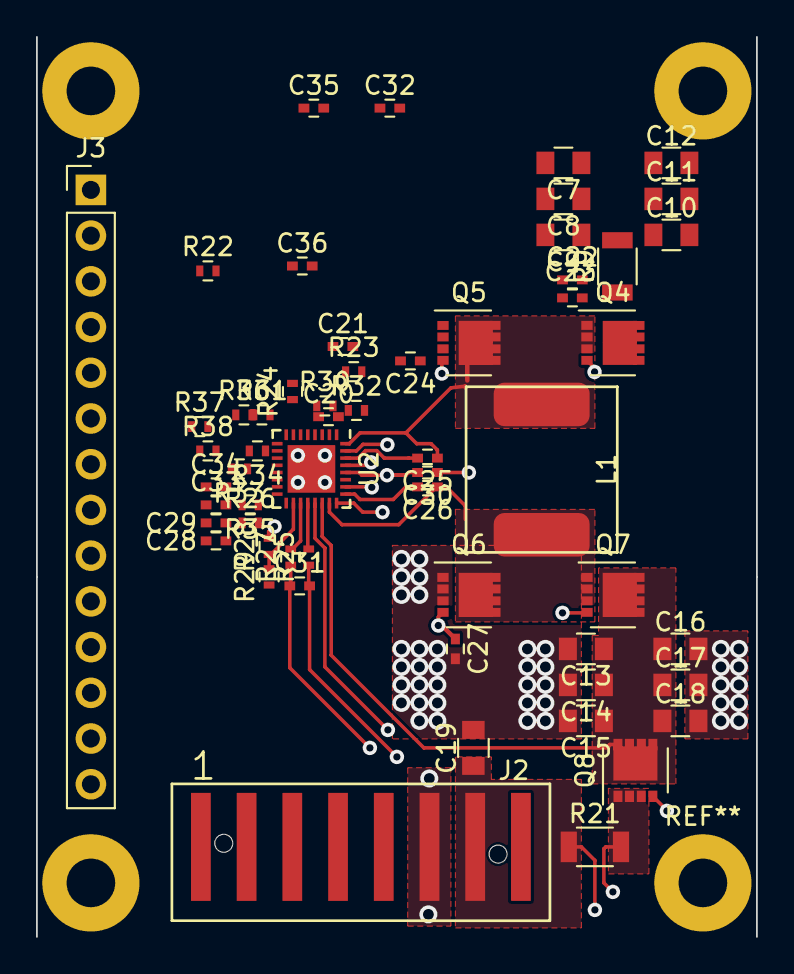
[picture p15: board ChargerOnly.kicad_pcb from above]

Board: 4 copper layers, 40.0 x 50.0 mm, 58 parts (0 on the bottom side), 35 nets.

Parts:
C7, C8, C9, C10, C11, C12, C13, C14, C15, C16, C17, C18: 10uF; C_0805
C19: 10uF 25V; C_0805
C20, C21: 0.033uF; C_0402
C22: 0.01uF; C_0402
C23: 0.001uF; C_0402
C24, C27: 150pF; C_0402
C25, C26: 0.047uF; C_0402
C28: 15pF; C_0402
C29: 680pF; C_0402
C30: 2.2uF; C_0402
C31: 0.1uF; C_0402
C32: 1uF; C_0402
C33: 33pF; C_0402
C34: 1800pF; C_0402
C35, C36: 100pF; C_0402
J2: Conn_01x06; 14110613002XXX
J3: Conn_01x14; Pin_Header_Straight_1x14_Pitch2.54mm
L1: 2.2uH; WE-LHMI-8030
Q4, Q5, Q6, Q7: CSD17309Q3; VSON-8_3.3x3.3mm_Pitch0.65mm_NexFET
Q8: P-FET; VSON-8_3.3x3.3mm_Pitch0.65mm_NexFET
R9, R21: 0.010R; R_1206
R22, R23: 4.99R; R_0402
R24, R25, R27: 10R 1%; R_0402
R26, R32, R33, R34, R36: 10K 1%; R_0402
R28: 100K 1%; R_0402
R29: 301K 1%; R_0402
R30: 383K 1%; R_0402
R31: 220K 1%; R_0402
R35: 40.2K 1%; R_0402
R37, R38: 137K 1%; R_0402
U2: bq27500A; QFN-32-1EP_4x4mm_Pitch0.4mm

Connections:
/Charger/ACN: C21.1, R23.2, U2.2
/Charger/ACP: C20.1, R22.2, U2.3
/Charger/CBP: R28.1, R29.2, U2.18
/Charger/CHRG_OK: R32.1, U2.4
/Charger/COMP1: C34.2, R35.1, U2.16
/Charger/COMP2: C28.1, R26.2, U2.17
/Charger/IADPT: C36.2, R38.2, U2.8
/Charger/IBAT: C35.1, U2.9
/Charger/ILIM_HIZ: R30.1, R31.2, U2.6
/Charger/L1-L: C25.1, L1.2, Q4.1, Q4.2, Q4.3, Q5.5, U2.32
/Charger/L1-R: C26.1, L1.1, Q6.5, Q7.1, Q7.2, Q7.3, U2.23
/Charger/PSYS: R37.1, U2.10
/Charger/REGN: C30.2, R24.2, R28.2, U2.28
/Charger/SCL: R34.1, U2.13
/Charger/SDA: R33.1, U2.12
/Charger/SRN: R27.2, U2.19
/Charger/SRP: R25.2, U2.20
/Charger/VBAT: C19.1, C31.1, J2.6, R21.1, R27.1
/Charger/VBUS: C7.1, C8.1, C9.1, C10.1, C11.1, C12.1, R9.2, R22.1
/Charger/VDDA: C32.2, R24.1, R30.2, U2.7
/Charger/VSYS: C13.1, C14.1, C15.1, C16.1, C17.1, C18.1, Q7.5, Q8.5, U2.22
/Charger/~BATDRV~: Q8.4, U2.21
/Charger/~PROCHOT~: R36.1, U2.11
GND: C7.2, C8.2, C9.2, C10.2, C11.2, C12.2, C13.2, C14.2, C15.2, C16.2, C17.2, C18.2, C19.2, C20.2, C21.2, C22.1, C23.1, C24.2, C27.2, C28.2, C29.2, C30.1, C32.1, C33.1, C34.1, C35.2, C36.1, J2.5, Q5.1, Q5.2, Q5.3, Q6.1, Q6.2, Q6.3, R29.1, R31.1, R37.2, R38.1, U2.14, U2.27, U2.33
unnamed: C22.2, C23.2, Q4.5, R9.1, R23.1, U2.1
unnamed: C24.1, Q5.4, U2.29
unnamed: C25.2, U2.30
unnamed: C26.2, U2.25
unnamed: C27.1, Q6.4, U2.26
unnamed: C29.1, R26.1
unnamed: C31.2, Q8.1, Q8.2, Q8.3, R21.2, R25.1
unnamed: C33.2, R35.2
unnamed: Q4.4, U2.31
unnamed: Q7.4, U2.24
unnamed: R32.2, R33.2, R34.2, R36.2

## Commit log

2017-07-31 Some updates, net-ties and such.
    [SB-4S5A.kicad_pcb, SB-4S5A.sch]
2017-08-07 Added battery footprint
    [SB-4S5A.kicad_pcb, SB-4S5A.sch]
2017-08-07 Started board layout.
    [SB-4S5A.kicad_pcb]
2017-08-08 Add simple battery 3d model, more layout.
    [SB-4S5A.kicad_pcb]
2017-08-27 Finish place and routing.
    [SB-4S5A.kicad_pcb, SB-4S5A.sch]
2017-08-27 Fix missing vias on VC2A
    [SB-4S5A.kicad_pcb]
2017-08-27 Move kelvin connection for VC3A to the correct place.
    [SB-4S5A.kicad_pcb]
2018-01-13 Convert to "KiCad 5.0" format.
    Other stuff
    [ChargerOnly.kicad_pcb, SB-4S5A.kicad_pcb, SB-4S5A.sch]
2018-04-03 Almost done, can't freaking decide on a connector...
    [SB-4S5A.kicad_pcb, SB-4S5A.sch]
2018-04-03 Ready to send to manufacturer.
    [SB-4S5A-BOM.ods, SB-4S5A-BOM.xlsx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]
2018-04-05 Sent to manuf
    [SB-4S5A-BOM.ods, SB-4S5A-BOM.xlsx]
2018-04-10 Add P&P pos file.
    [SB-4S5A-all-pos.csv]
2018-06-29 Fix FUSE pin floating.
    [SB-4S5A.kicad_pcb, SB-4S5A.sch]
